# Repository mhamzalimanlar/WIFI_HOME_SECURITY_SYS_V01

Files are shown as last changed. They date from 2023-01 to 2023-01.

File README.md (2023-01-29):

# WIFI_HOME_SECURITY_SYS_V01
 
The system is designed with a 220V AC input and a 12-5V DC output. A DB105STR bridge diode, an STM41T00M6F RTC module for clock information, and a MicroUSB type-B interface are used. The system also features a MAX6662 temperature sensor for indoor temperature control, a TFPT PTC thermistor for outdoor temperature control, and a LHI-878 PIR sensor for motion control in the outdoor environment. The PIR sensor is controlled by a NCS36000 controller. There are two 12V relays for lighting control and an ESP32 WiFi module for wireless communication. Communication between the main microcontroller (STM32f103) and these components is established through the USART, SPI and I2C protocols. The design includes two PCBs: one for the main board and one for the auxiliary sensor board. The boards have 2 layers for signals and 2 layers for power and ground planes, for a total of 4 layers. The design was created using the Altium Designer program.

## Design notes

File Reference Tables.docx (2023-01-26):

Voltage Range (V) | Internal Layers(mil) | External Layers(mil)
0-15 | >1.97 | >3.94
16-30 | >1.97 | >3.94
31-50 | >3.94 | >23.62
51-100 | >3.94 | >23.62
101-150 | >7.87 | >23.62
151-170 | >7.87 | >49.21
171-250 | >7.87 | >49.21
251-300 | >7.87 | >49.21
301-500 | >9.84 | >98.43
>500 | >9.94 | >98.62

Distance Between Lines According To The Voltage Level

Calculated with IPC-2221B VALUES

Capacity Of Current According To The Lınes Wıthdes

Current Capacity(A) | Internal Layers(mil) | External Layers(mil)
<0.94 | 10 | 10
<1.23 | 15 | 15
<1.47 | 20 | 20
<1.69 | 25 | 25
<1.89 | 30 | 30
<2.08 | 35 | 35
<2.25 | 40 | 40
<2.42 | 45 | 45
<2.58 | 50 | 50
<2.73 | 55 | 55
<3.15 | 70 | 70

Calculated with IPC-21525 VALUES (Material FR-4 STD)

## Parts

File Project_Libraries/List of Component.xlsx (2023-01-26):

Comment | Description | Footprint
1N4148WS | Diode, Single, 75 V, 150 mA, 1 V, 4 ns | SOD323F
1SMB5919BT3G | Diode Zener Single 5.6V 5% 3W 2-Pin SMB T/R | SMB
5WD27 | Resistor 5 Watt Cermet Wirewound Flameproof .27 Ohm 5% Axial Lead | RES_AXIAL_W
0603B103K160CT | CAP CER 10nF %10 0603 | CAP_0603
0603B103K160CT | CAP CER 10nF %10 0603 | CAP_0603
10118192-0001LF | CONN RCPT USB2.0 MICRO B SMD R/A | MICRO_B_USB
3413.0216.22 | FUSE BRD MNT 1A 32VAC 63VDC 1206 | 3413.0216.22
64800611622 | 1.50mm 6PIN Connector | 64800611622
78438335470 | FIXED IND 47UH 390MA 2.3 OHM SMD | IND_1212
ABS05-32.768KHZ-T | Crystal, 32.768 kHz, SMD, 1.6mm x 1mm, 12.5 pF, 20 ppm, ABS05 Series | ABS05
ALQ112 | General Purpose Relay SPDT (1 Form C) 12VDC Coil Through Hole | ALQ112
AP7361-33E-13 | LDO Regulator Pos 3.3V 1A 4-Pin(3+Tab) SOT-223 T/R | SOT223
BV302S12010-ZU | 230-12 Transformer 1VA | BV302S
C0603C104K5RACTU | CAP CER 100nF %10 0603 SMD | CAP_0603
C3216X5R1E336M160AC | CAP CER 33uF %20 1206 SMD | CAP_1206
CL10C200JB8NNNC | CAP CER 20pF %5 0603 SMD | CAP_0603
CL21A475KAQNNNE | CAP CER 4.7uF %10 0805 | CAP_0805
CL21B104KBCNNNC | CAP CER 100nF %10 0805 | CAP_0805
CL21B105KBFNNNE | CAP CER 1uF %10 0805 | CAP_0805
CMI-9605IC-0580T | Buzzers Indicator, Internally Driven Magnetic 5V 30mA 2.7kHz 80dB @ 5V, 10cm Through Hole PC Pins | CMI-9605IC
DB105STR | Bridge Diode AC-DC | DB105STR
ECS-160-20-30B-TR | CRYSTAL 16.0000MHZ 20PF SMD | ECS
EEV686M035A9HAA | Cap Aluminum Lytic 68uF 35V 20% (6.3 X 7.7mm) SMD 280mA 2000h 105C T/R | CAP_EEVseries
EG1215AA | Slide Switch, SPDT, 0.025A, 24V, SMD | EG1215AA
ESH477M050AH4AA | CAP ALU ELEC 470uF 50V RADIAL, Cap, 470UF, 50V, Alu Elec, Radial | CAP_RADIAL_D10_P5
ESP32-WROOM-32 | SMD MODULE, ESP32-D0WDQ6, 32MBIT | ESP32-32
LH R974-LP-1 | LED Uni-Color Hyper Red 660nm 2-Pin Chip 0805(2012Metric) T/R | LED_RED_0805
LHI 878/3902 | SENSOR PYRO DETECTOR DUAL MOTION | LHI 878
LM2675MX-12/NOPB | Switching Voltage Regulators Pwr Cnvtr Hi Eff 1A SD Vtg Reg | SOIC8
LTST-C171GKT | Green 0805 130 º Min 5 mcd Typical 12 mcd Water Clear Lens SMT LED | LED_GREEN_0805
M41T00M6F | IC RTC CLK/CALENDAR I2C 8-SOIC | SOIC8
MAX6662 | SENSOR TEMPERATURE SPI 8SOIC | SOIC8
MMBT3904-7-F | Transistor General Purpose BJT NPN 40 Volt 0.2A Automotive 3-Pin SOT-23 | SOT-23F
NCS36000DRG | PIR Controller Low Noise Amplifiers and LDO Regulator 14-Pin SOIC N T/R | SOIC14
OPA314AIDBVR | Op Amp OPA314 | SOT23-5
PJ-037AH-SMT-TR | DC Power Connectors Power Jacks | JACK
RC0603FR-0710KL | RES 1K %1 OHM 0603 SMD, RES 10K %1 OHM 0603 SMD | RES_0603
RC0603JR-070RL | RES 0 %1 OHM 0603 SMD | RES_0603
RC0603JR-074K7L | RES 4K7 %5 OHM 0603 SMD | RES_0603
RC0603JR-0715RL | RES 15 %5 OHM 0603 SMD | RES_0603
RC0603JR-0743KL | RES 43K %5 OHM 0603 SMD | RES_0603
RC0603JR-07100RL | RES 100 %5 OHM 0603 SMD | RES_0603
RC0603JR-07220KL | RES 220K %5 OHM 0603 SMD | RES_0603
RC0603JR-07560KL | RES SMD 560K OHM 5% 1/10W 0603 | RES_0603
SMH-105-02-L-S | .100 C.L. HORIZONTAL SMT SOCKET | PINHEADER1X5_RA
STM32F103C6T6A | MCU 32-bit STM32F ARM Cortex M3 RISC 32KB Flash 2.5V/3.3V 48-Pin LQFP Tray | LQFP-48
TBP01R1-508-02BE | Conn Shrouded Header HDR 2 POS 5.08mm Solder RA Side Entry Thru-Hole Bag | TBP01R1-508
TFPT1206L1002FM | Thermistor PTC 10K Ohm 1% 1206 | RES_1206
USBLC6-2SC6 | TVS DIODE 5.25V 17V SOT23-6 | SOT23-6L

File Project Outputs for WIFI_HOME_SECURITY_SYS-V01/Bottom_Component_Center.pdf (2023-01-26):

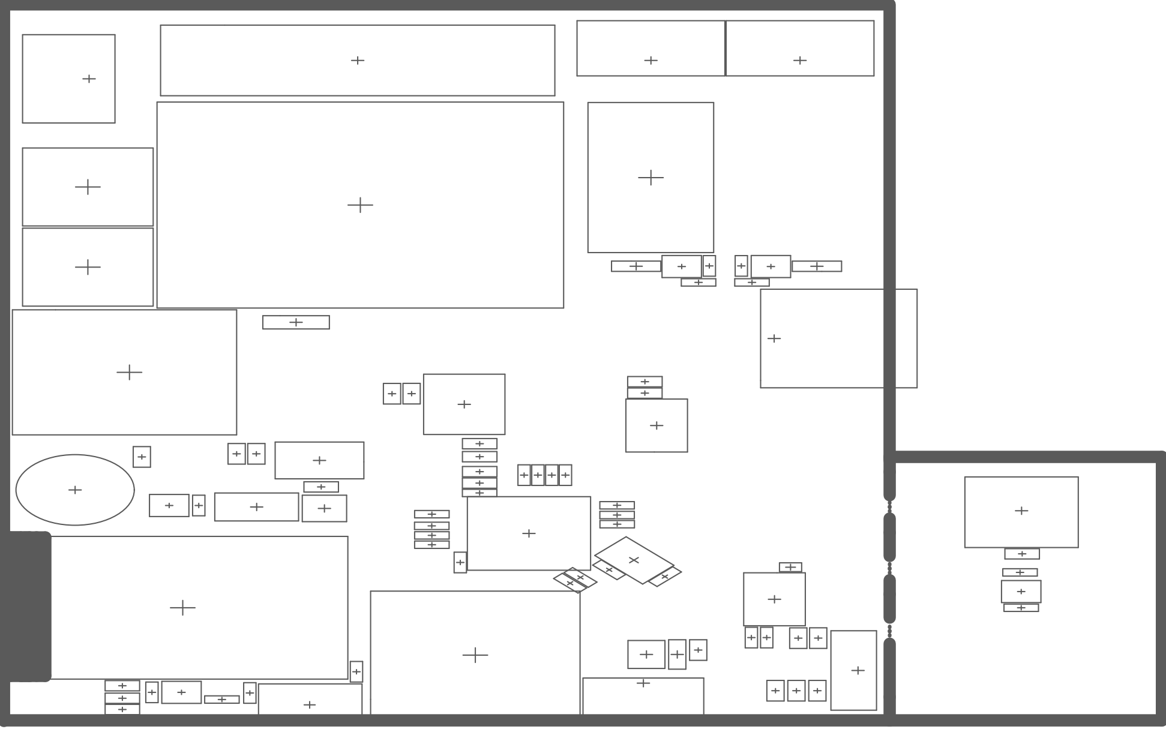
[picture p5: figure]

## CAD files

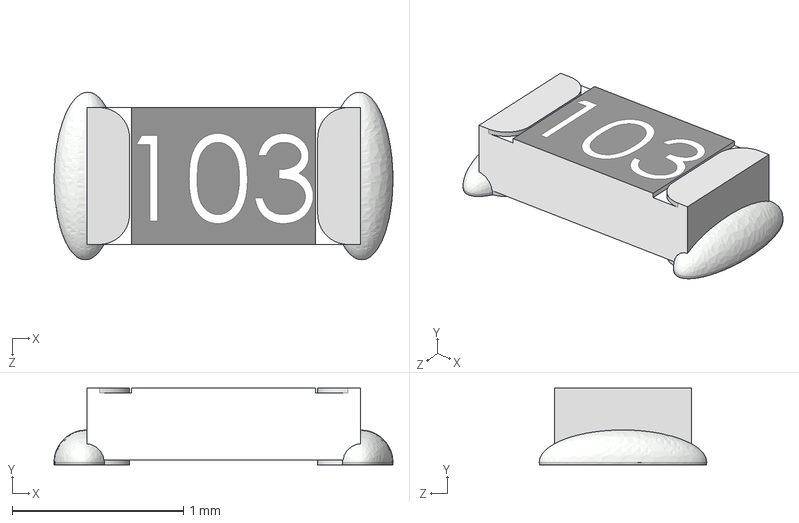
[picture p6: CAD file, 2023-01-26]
Project_Libraries/Steps/0603S1.STEP
1.98 x 0.45 x 0.979 mm

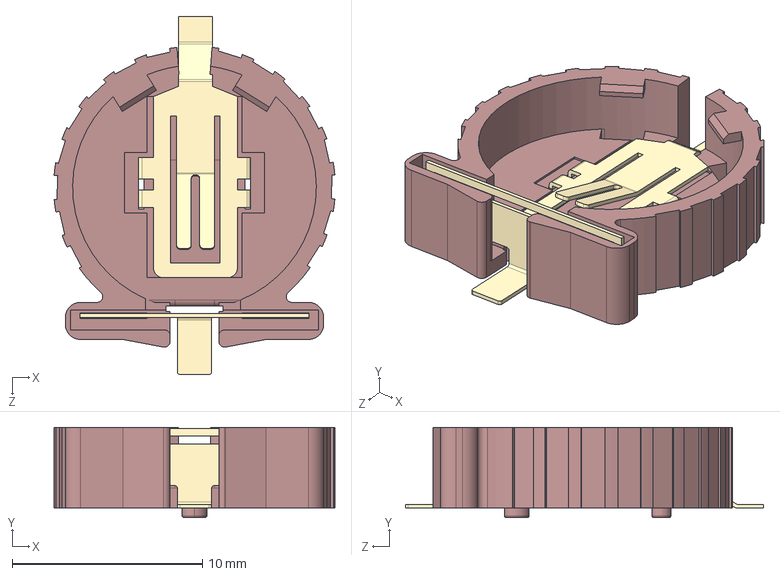
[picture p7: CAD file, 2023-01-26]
Project_Libraries/Steps/User Library-Battery Holder for CR1220 SMD.step
14.7 x 4.75 x 18.8 mm

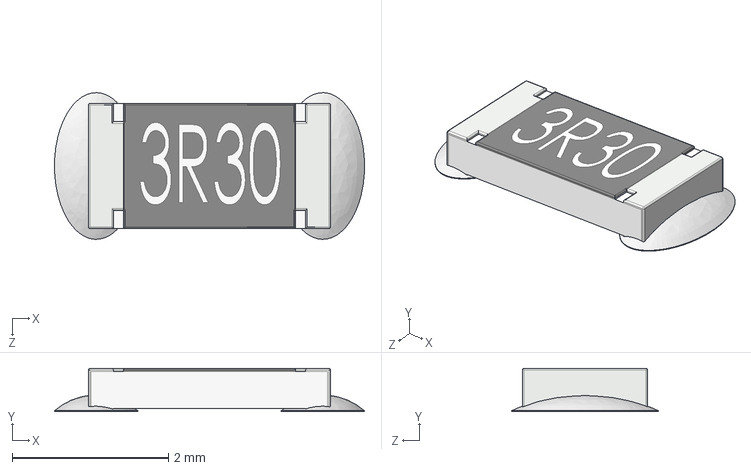
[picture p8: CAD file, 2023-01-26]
Project_Libraries/Steps/res1206r.STEP
3.97 x 0.551 x 1.88 mm

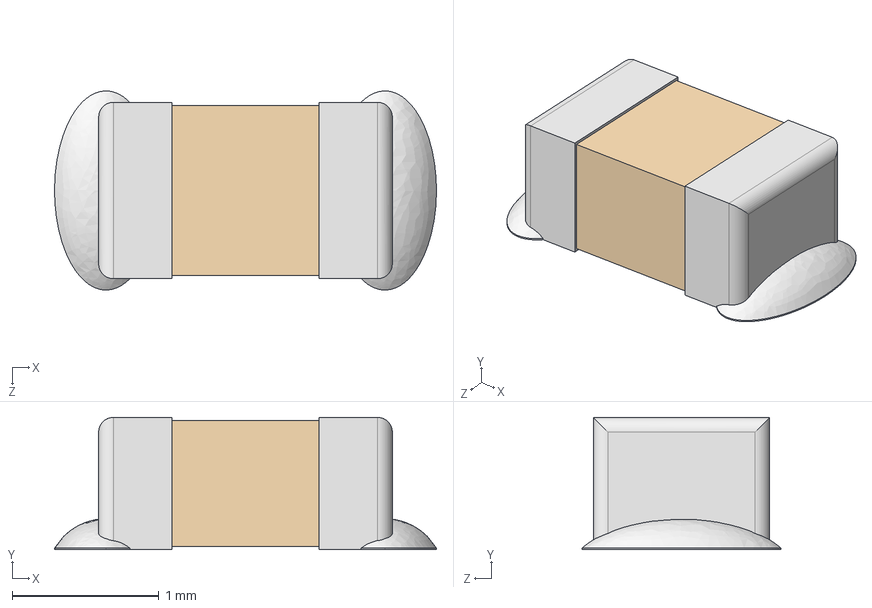
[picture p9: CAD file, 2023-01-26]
Project_Libraries/Steps/CAPC0805.STEP
2.60 x 0.9 x 1.36 mm

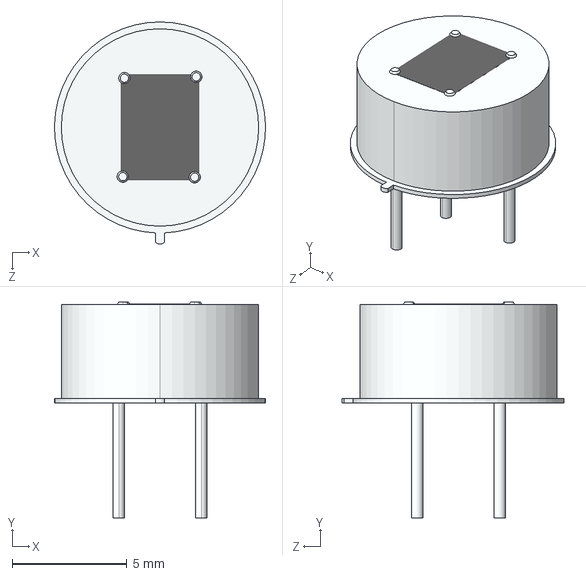
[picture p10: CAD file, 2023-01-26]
Project_Libraries/Steps/Library-LHI878-1.step
9.20 x 9.40 x 9.68 mm

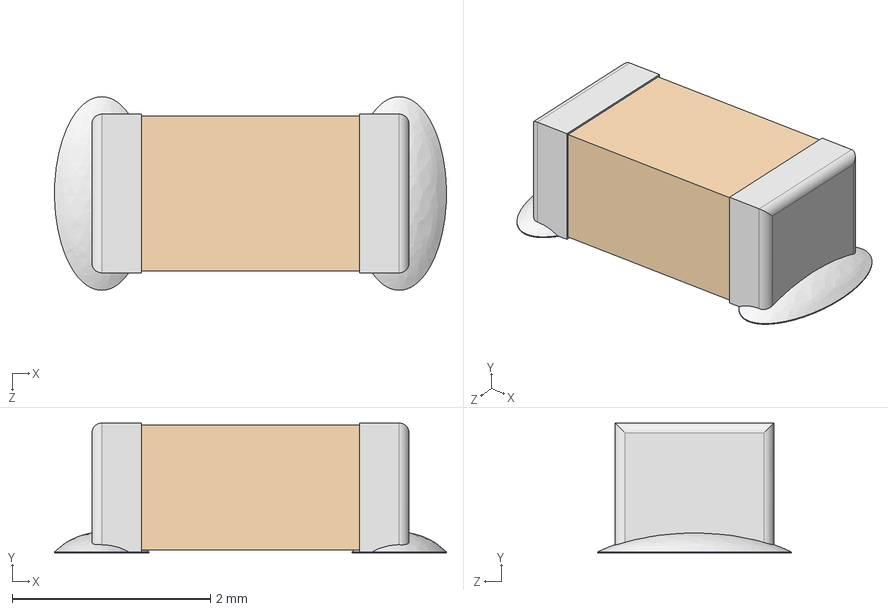
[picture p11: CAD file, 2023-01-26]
Project_Libraries/Steps/CAPC1206.STEP
3.95 x 1.31 x 1.95 mm

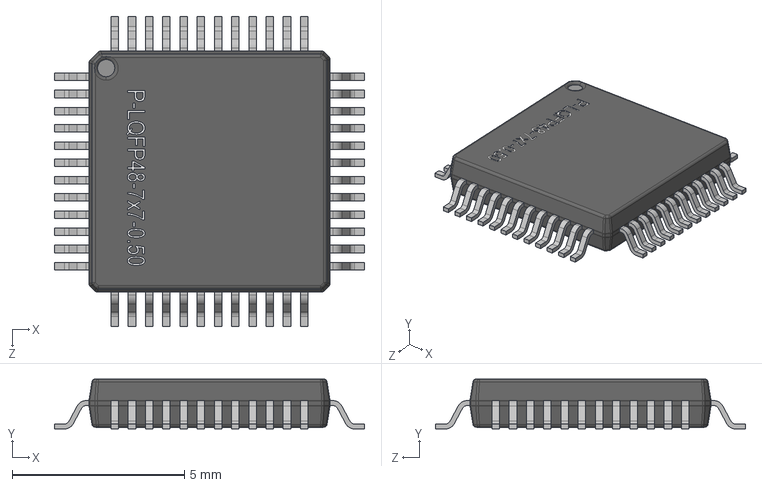
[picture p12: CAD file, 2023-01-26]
Project_Libraries/Steps/Library-P-LQFP48-7x7-0_50.step
9.00 x 1.45 x 9.00 mm

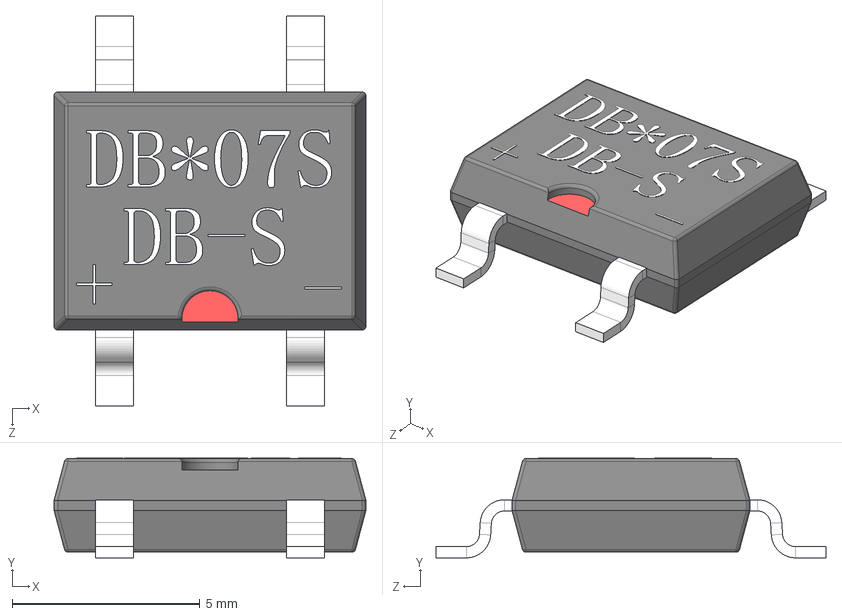
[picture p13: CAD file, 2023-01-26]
Project_Libraries/Steps/Library-DB107S DB-S.step
8.32 x 2.66 x 10.4 mm

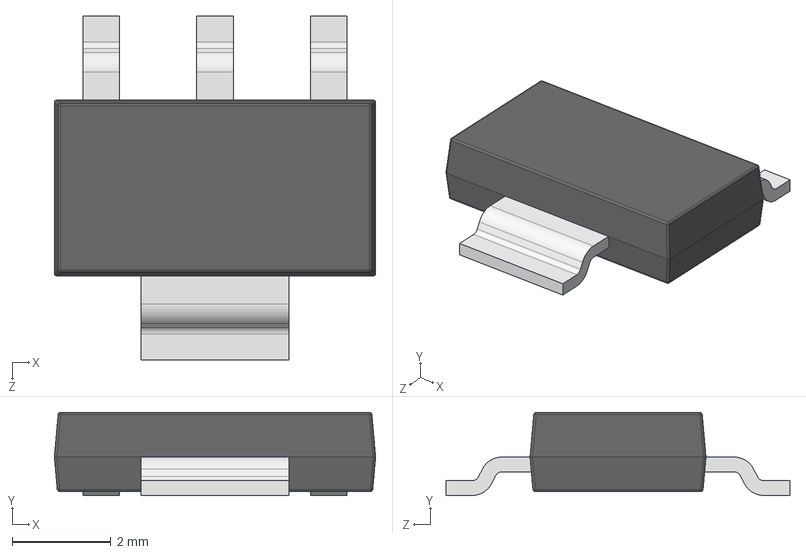
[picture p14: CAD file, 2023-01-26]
Project_Libraries/Steps/SOT-223.step
6.50 x 1.68 x 6.96 mm

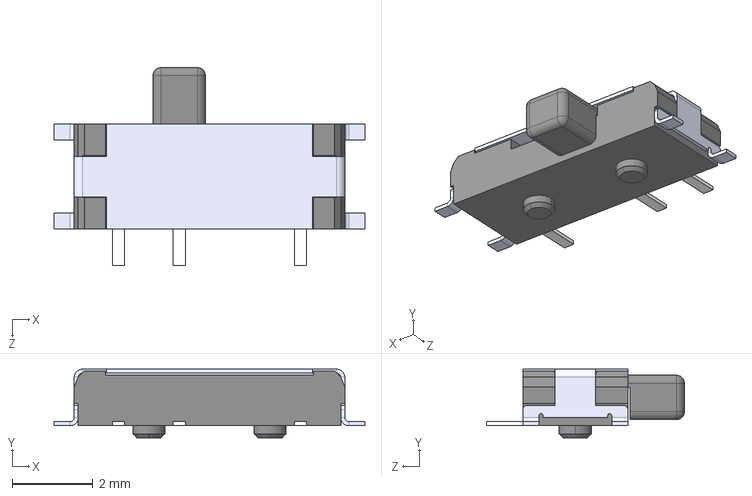
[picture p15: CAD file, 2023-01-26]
Project_Libraries/Steps/EG1215AA--3DModel-STEP-1.STEP
7.70 x 1.70 x 4.90 mm

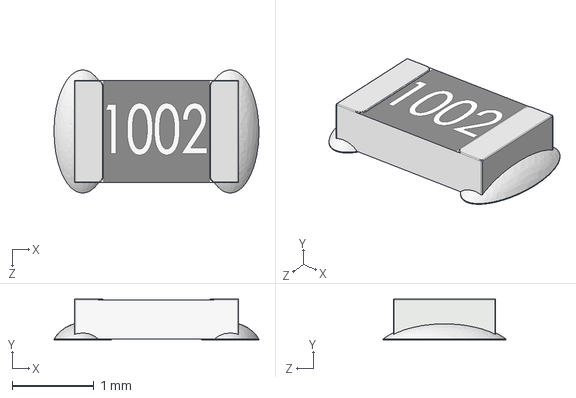
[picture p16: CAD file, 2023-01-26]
Project_Libraries/Steps/res0805.STEP
2.50 x 0.5 x 1.50 mm

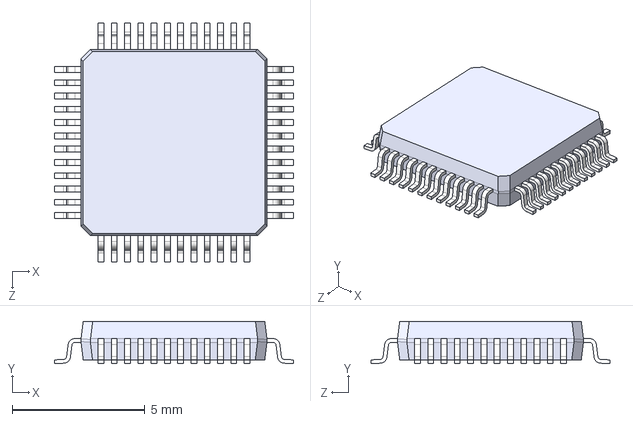
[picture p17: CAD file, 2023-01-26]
Project_Libraries/Steps/STM32F103C6T6A.STEP
9.00 x 1.60 x 9.00 mm

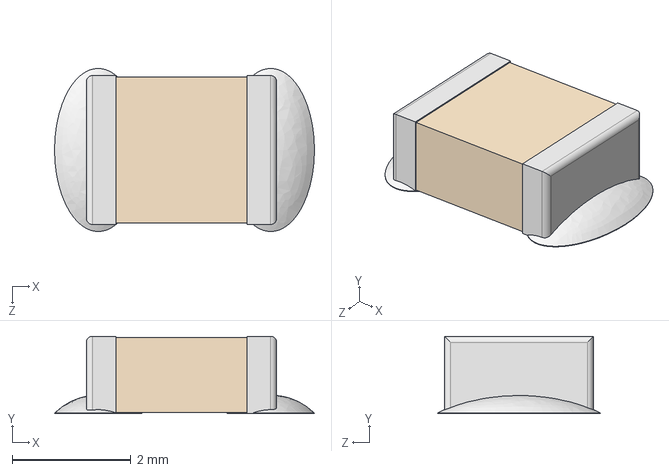
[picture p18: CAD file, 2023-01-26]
Project_Libraries/Steps/CAPC1210.STEP
4.37 x 1.30 x 2.74 mm

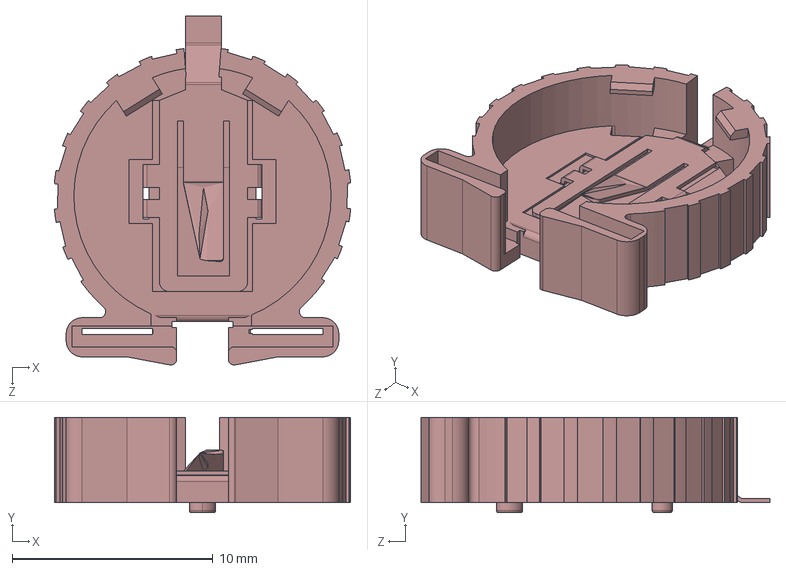
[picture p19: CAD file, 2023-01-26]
Project_Libraries/Steps/Library-1056.step
14.7 x 4.75 x 17.4 mm

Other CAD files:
Project_Libraries/Steps/LM2675M-12.STEP
Project_Libraries/Steps/Library-SOT23F-1.STEP
Project_Libraries/Steps/CAPC0603.STEP
Project_Libraries/Steps/Library-Hahn BV EI 302 2902.step
Project_Libraries/Steps/7447709001_Download_WE-PD_1210_STP_rev1_WE_INDUCTOR.stp
Project_Libraries/Steps/B82477G4472M000_COIL.STEP
Project_Libraries/Steps/STM32 LQFP48.step

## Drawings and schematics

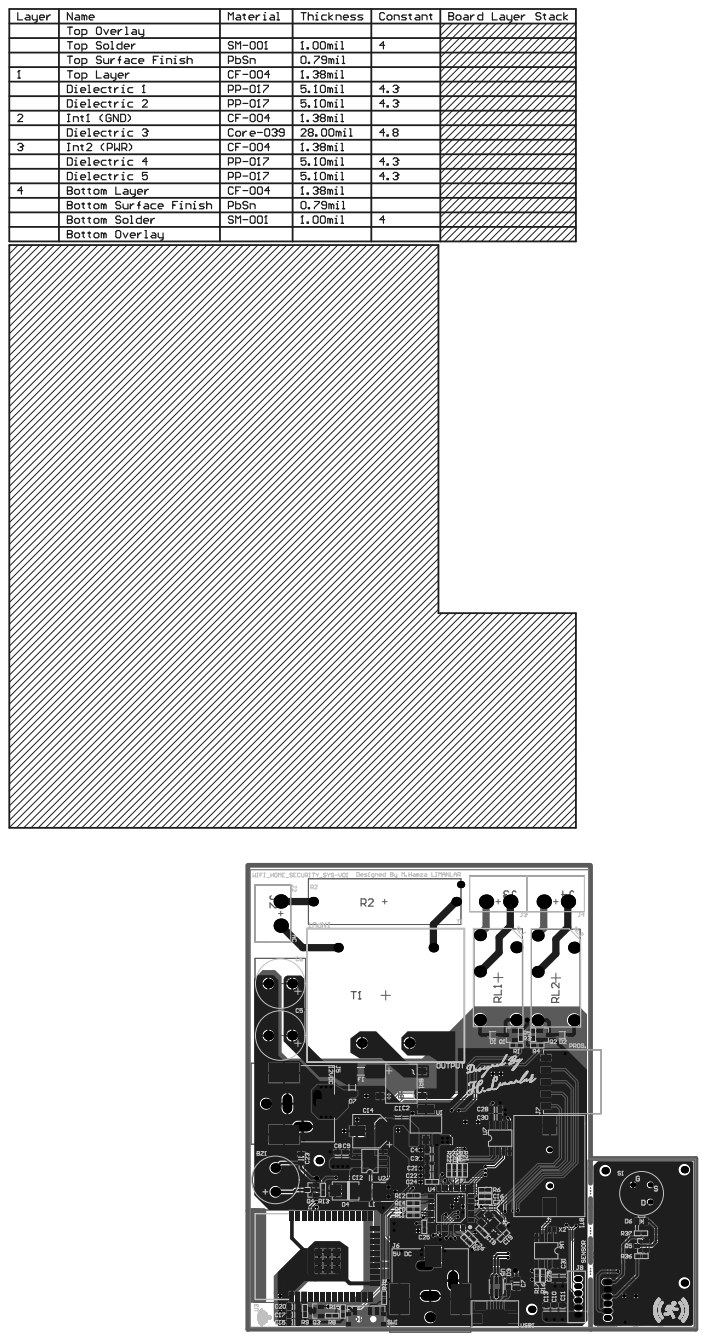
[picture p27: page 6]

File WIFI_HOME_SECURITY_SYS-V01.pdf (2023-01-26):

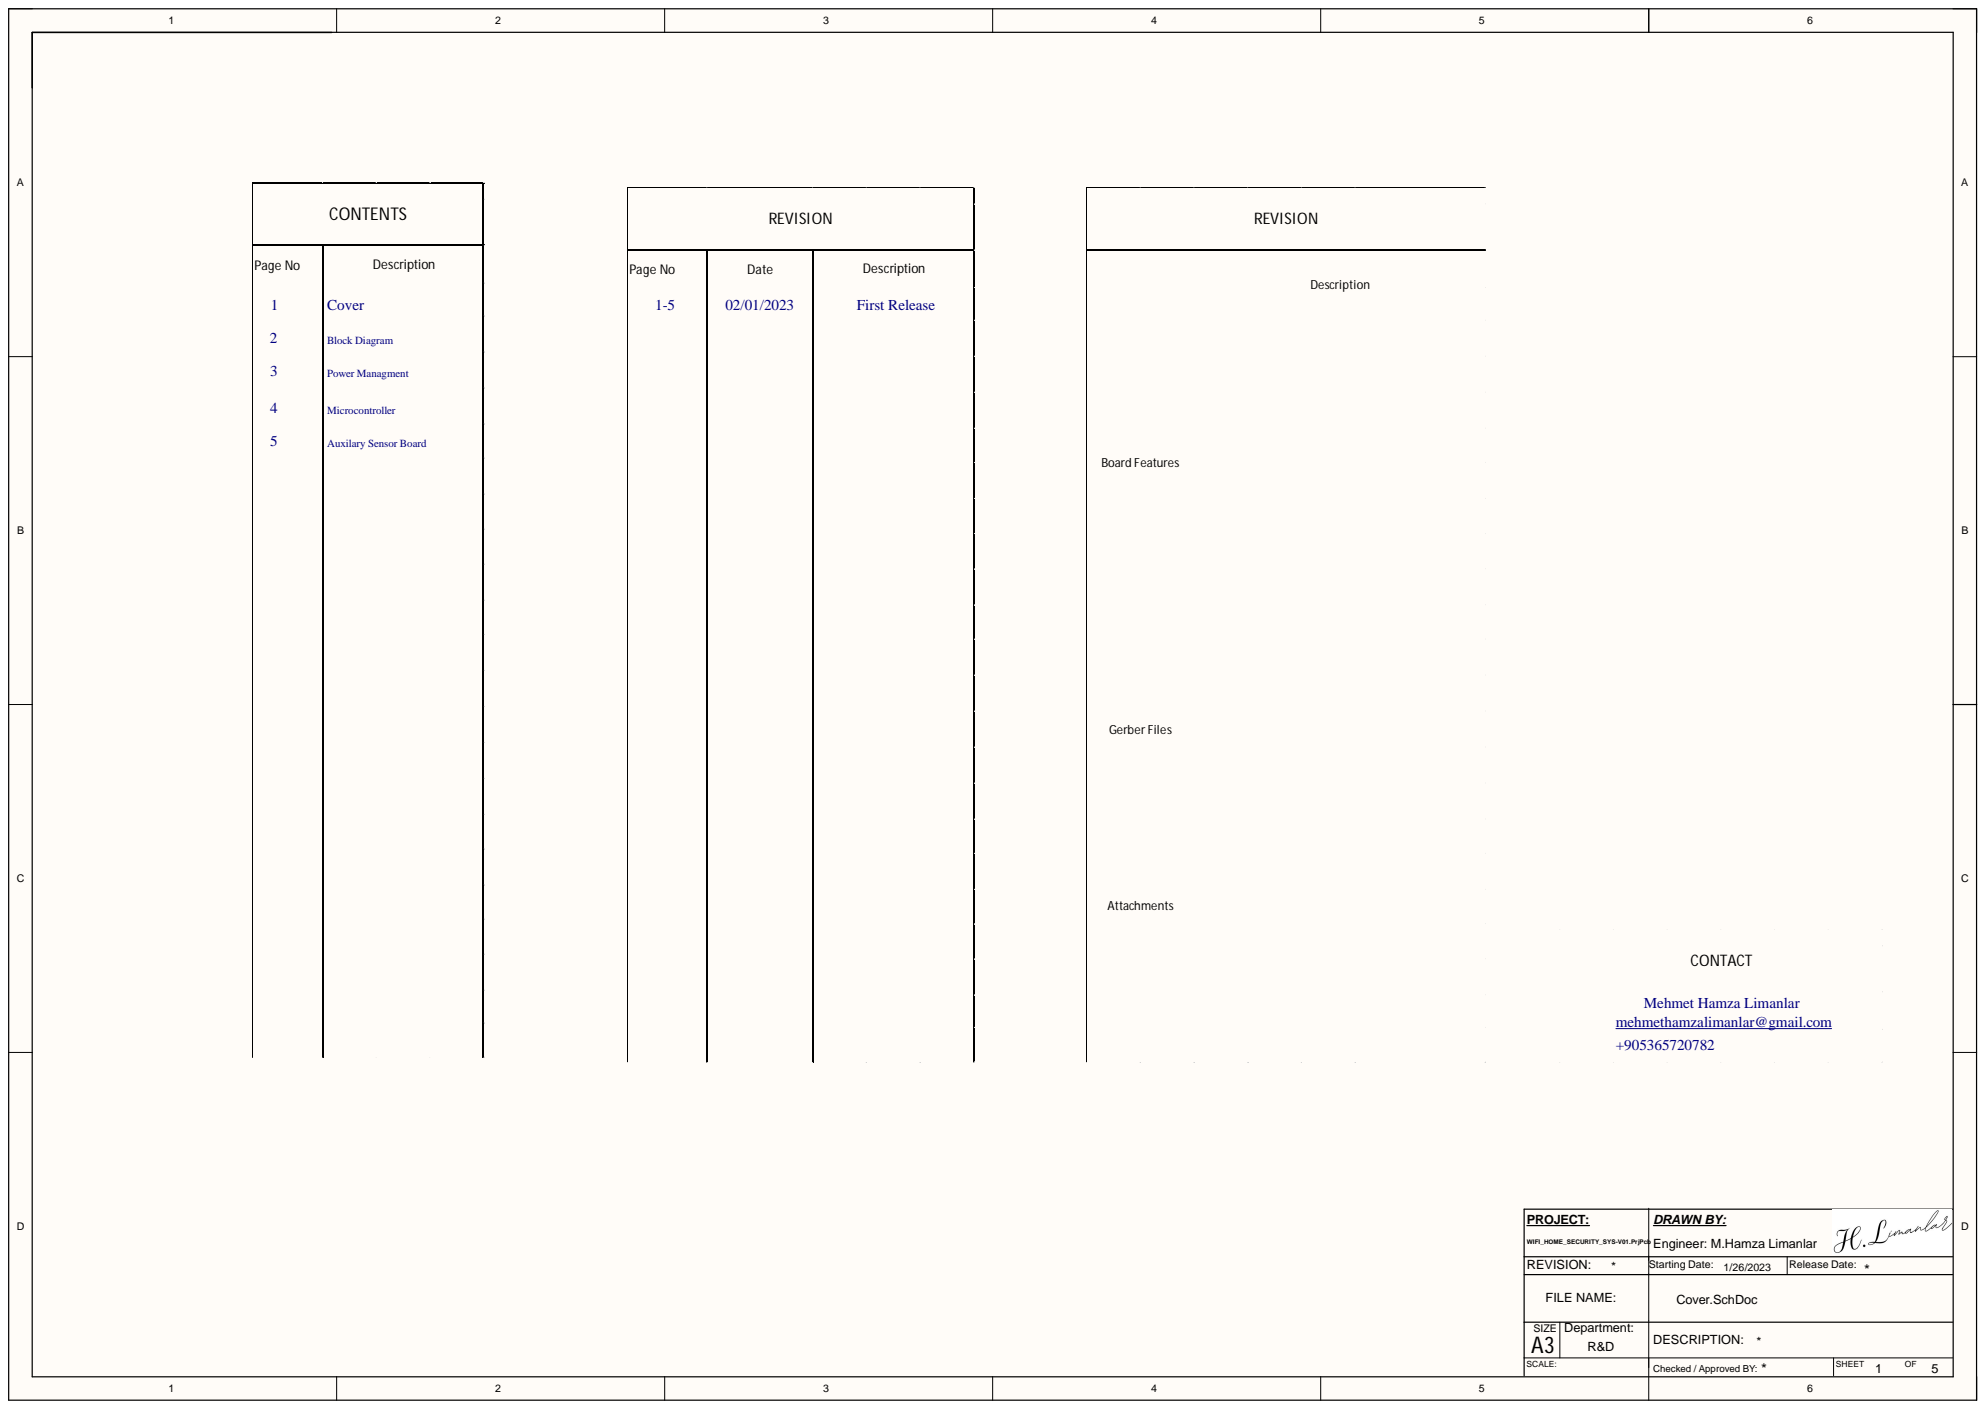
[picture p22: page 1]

PROJECT: WIFI_HOME_SECURITY_SYS-V01.PrjPcb | DRAWN BY: Engineer: M.Hamza Limanlar

REVISION: * | Starting Date: 1/26/2023 | Release Date: *

FILE NAME: | Cover.SchDoc
SIZE A3 | Department: R&D | DESCRIPTION: *

SCALE: | Checked / Approved BY: * | SHEET OF 5

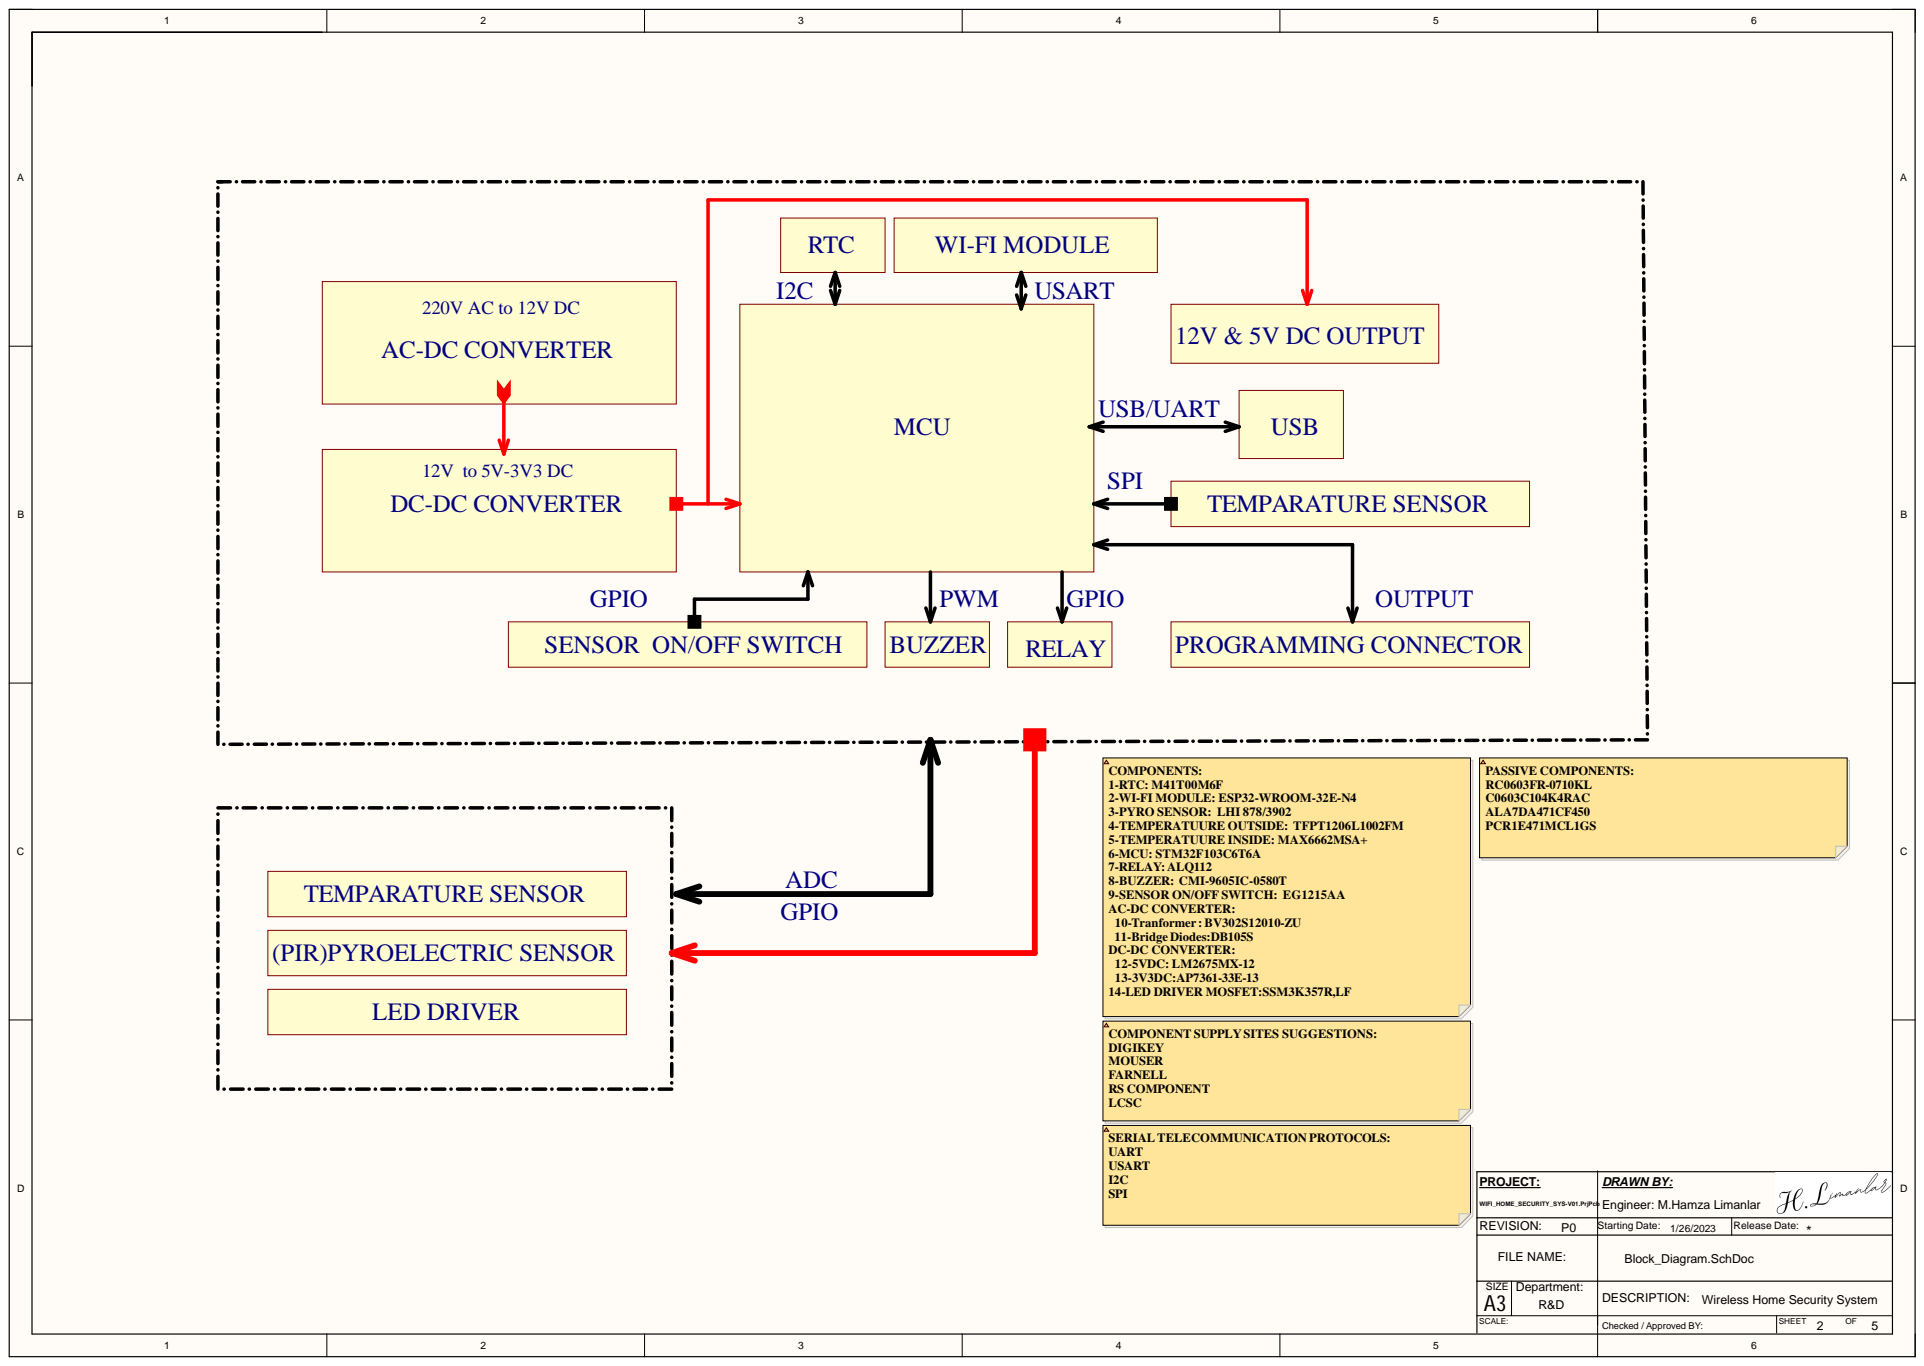
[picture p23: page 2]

COMPONENTS:
1-RTC: M41T00M6F
2-WI-FI MODULE: ESP32-WROOM-32E-N4
3-PYRO SENSOR: LHI 878/3902
4-TEMPERATUURE OUTSIDE: TFPT1206L1002FM
5-TEMPERATUURE INSIDE: MAX6662MSA+
6-MCU: STM32F103C6T6A
7-RELAY: ALQ112
8-BUZZER: CMI-9605IC-0580T
9-SENSOR ON/OFF SWITCH: EG1215AA
AC-DC CONVERTER:
10-Tranformer : BV302S12010-ZU
11-Bridge Diodes:DB105S
DC-DC CONVERTER:
12-5VDC: LM2675MX-12
14-LED DRIVER MOSFET:SSM3K357R,LF

PROJECT: WIFI_HOME_SECURITY_SYS-V01.PrjPcb | DRAWN BY: Engineer: M.Hamza Limanlar

REVISION: P0 | Starting Date: 1/26/2023 | Release Date: *

FILE NAME: | Block_Diagram.SchDoc
SIZE A3 | Department: | DESCRIPTION: Wireless Home Security System

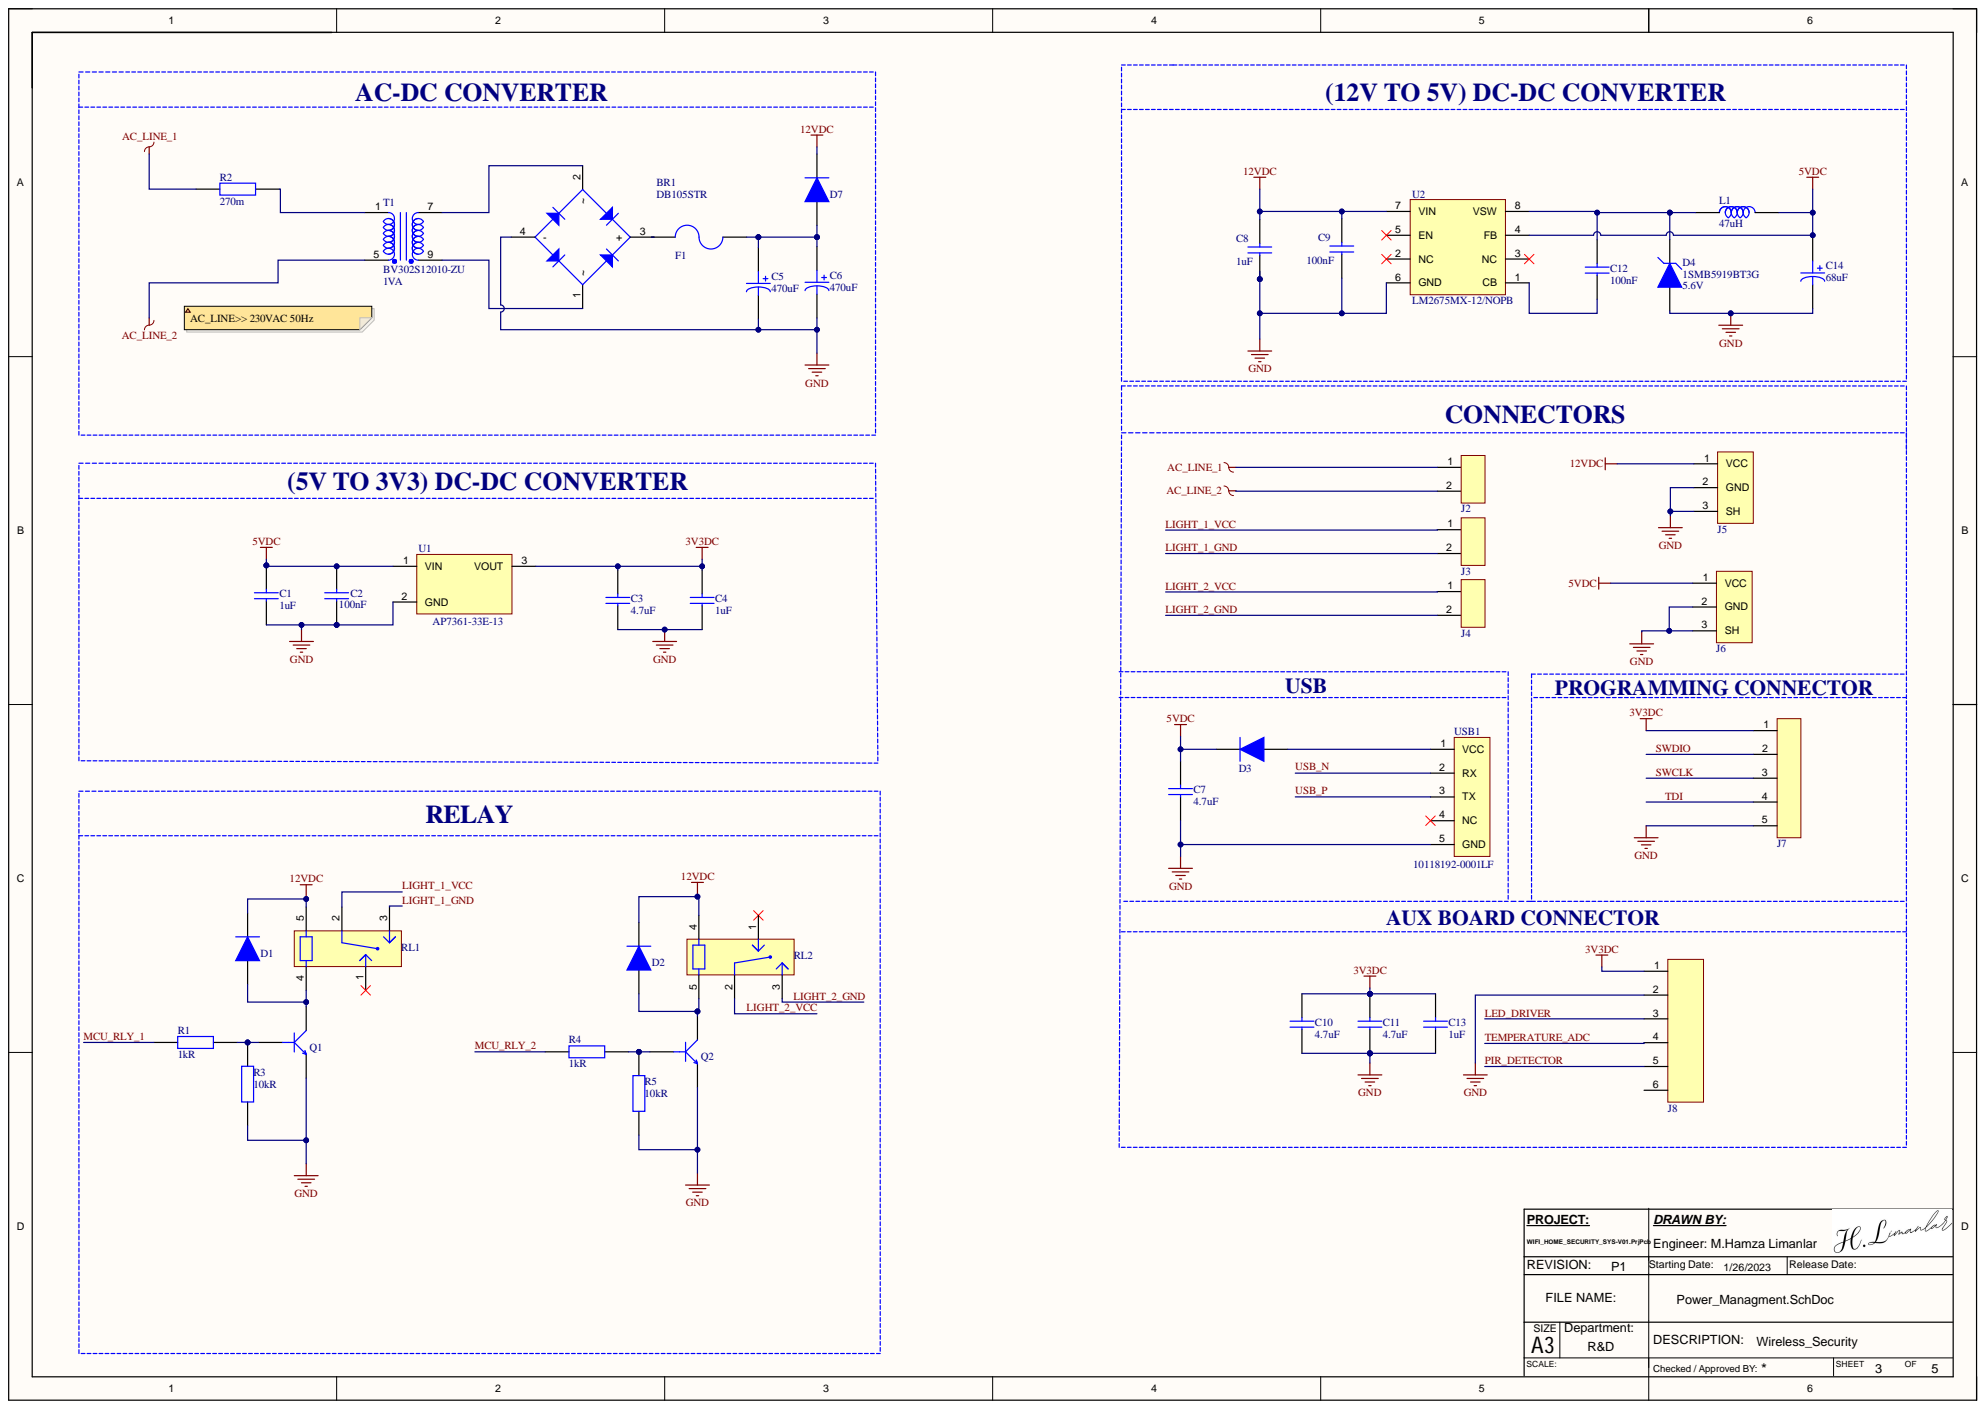
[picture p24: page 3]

(12V TO 5V) DC-DC CONVERTER

(5V TO 3V3) DC-DC CONVERTER

REVISION: P1 | Starting Date: 1/26/2023 | Release Date:

FILE NAME: | Power_Managment.SchDoc
SIZE A3 | Department: | DESCRIPTION: Wireless_Security

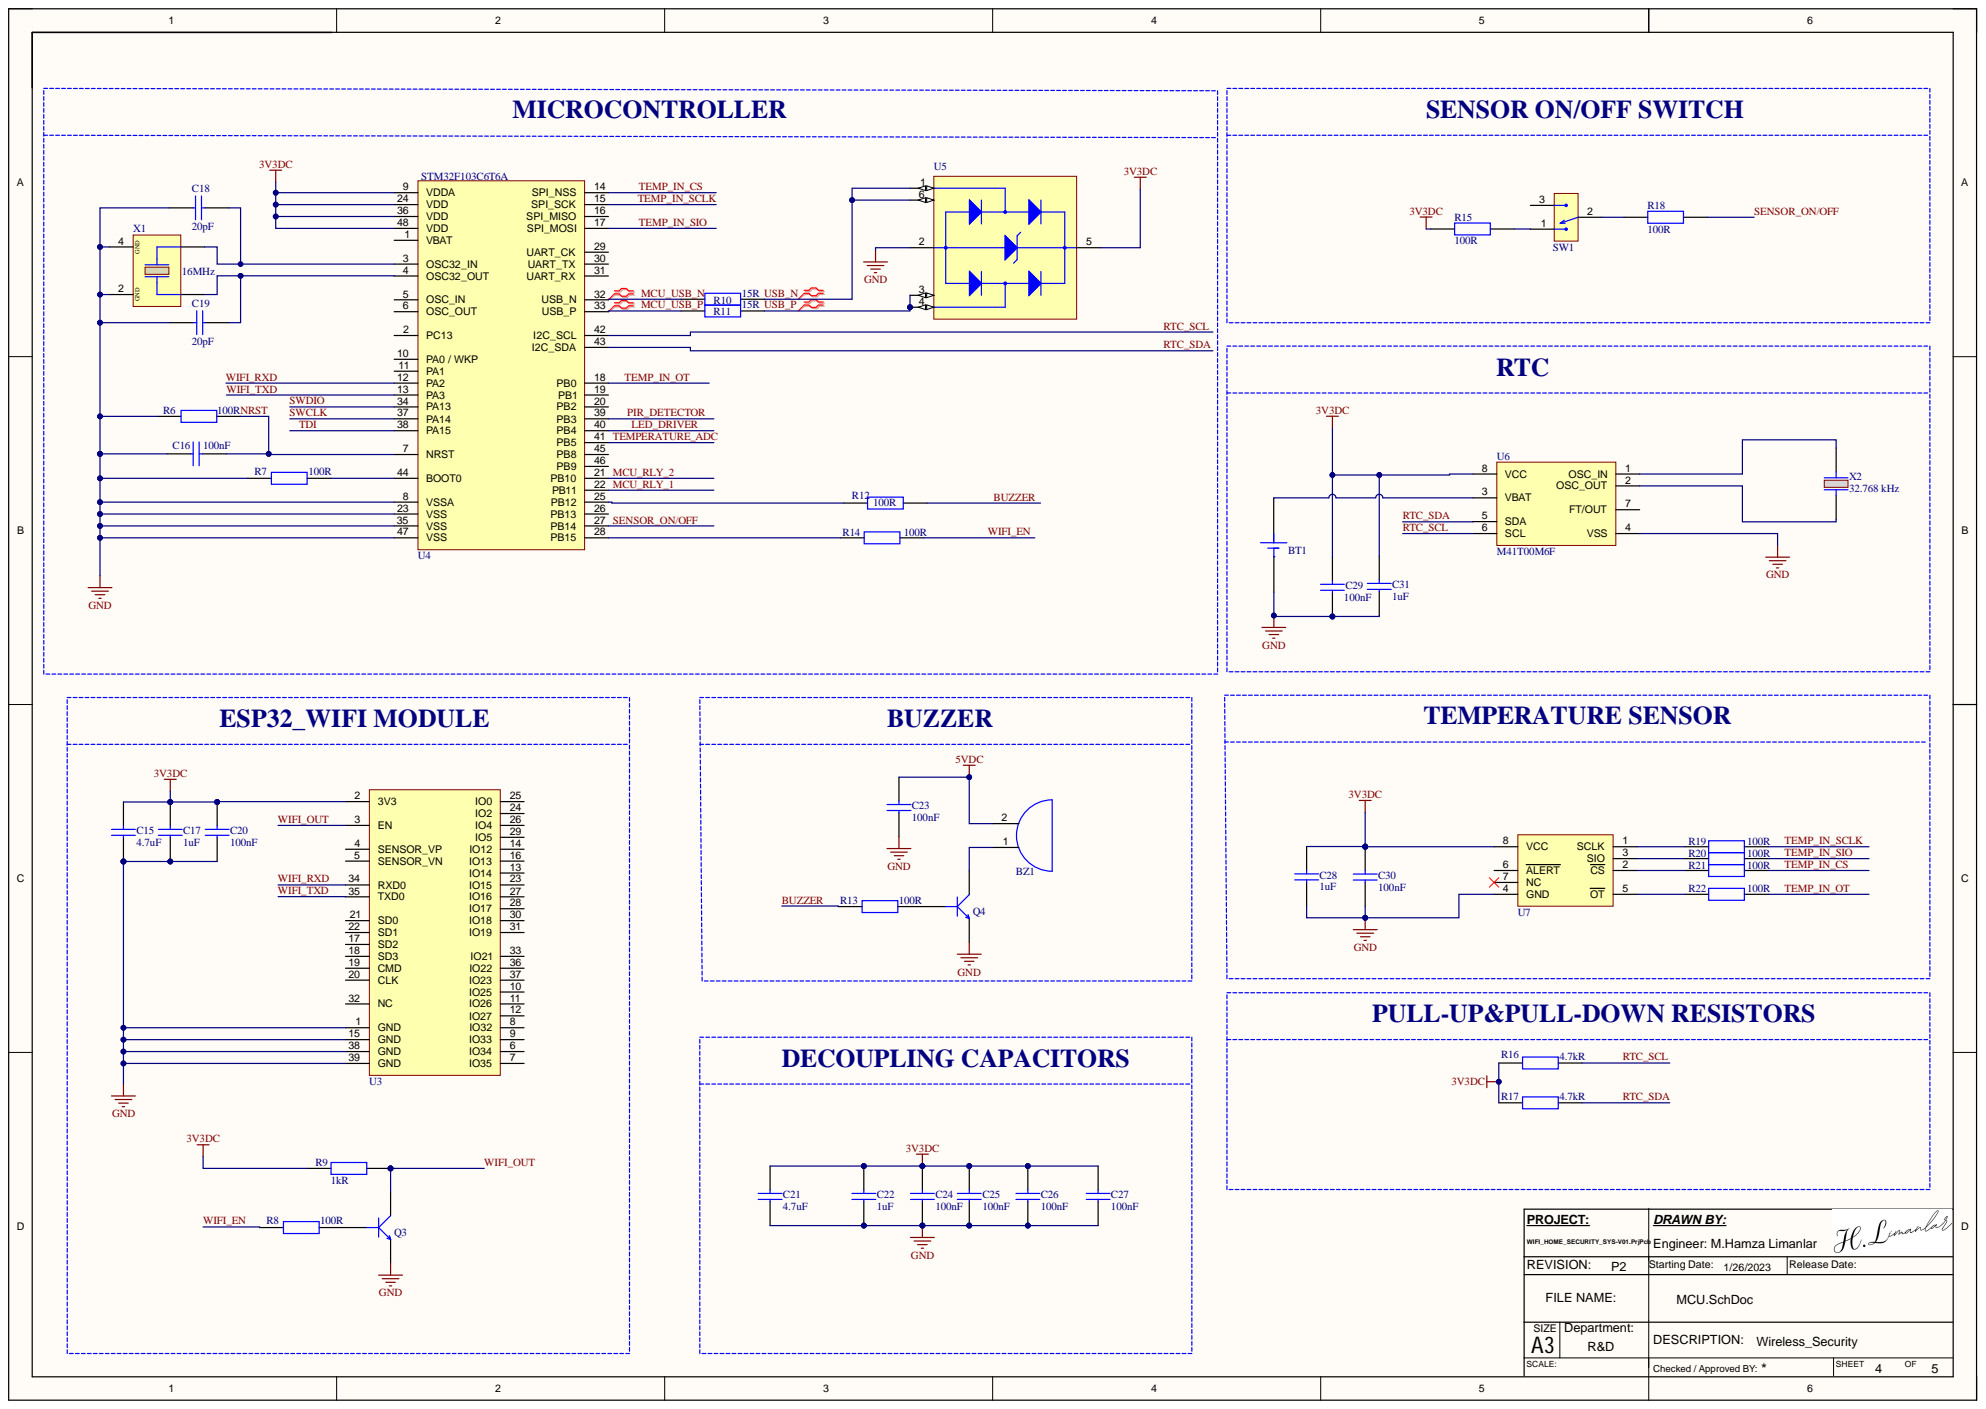
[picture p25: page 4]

SENSOR ON/OFF SWITCH

OSC32_OUT 4

OSC_OUT 6 | MCU_USB_P | 15R R10 15R R11 | USB_P | 4
OSC_IN 5

BOOT0 44

VSS 23 | | SCL 6
VSS 35
VSS 47

PULL-UP&PULL-DOWN RESISTORS

PROJECT: WIFI_HOME_SECURITY_SYS-V01.PrjPcb | DRAWN BY: Engineer: M.Hamza Limanlar

REVISION: P2 | Starting Date: 1/26/2023 | Release Date:

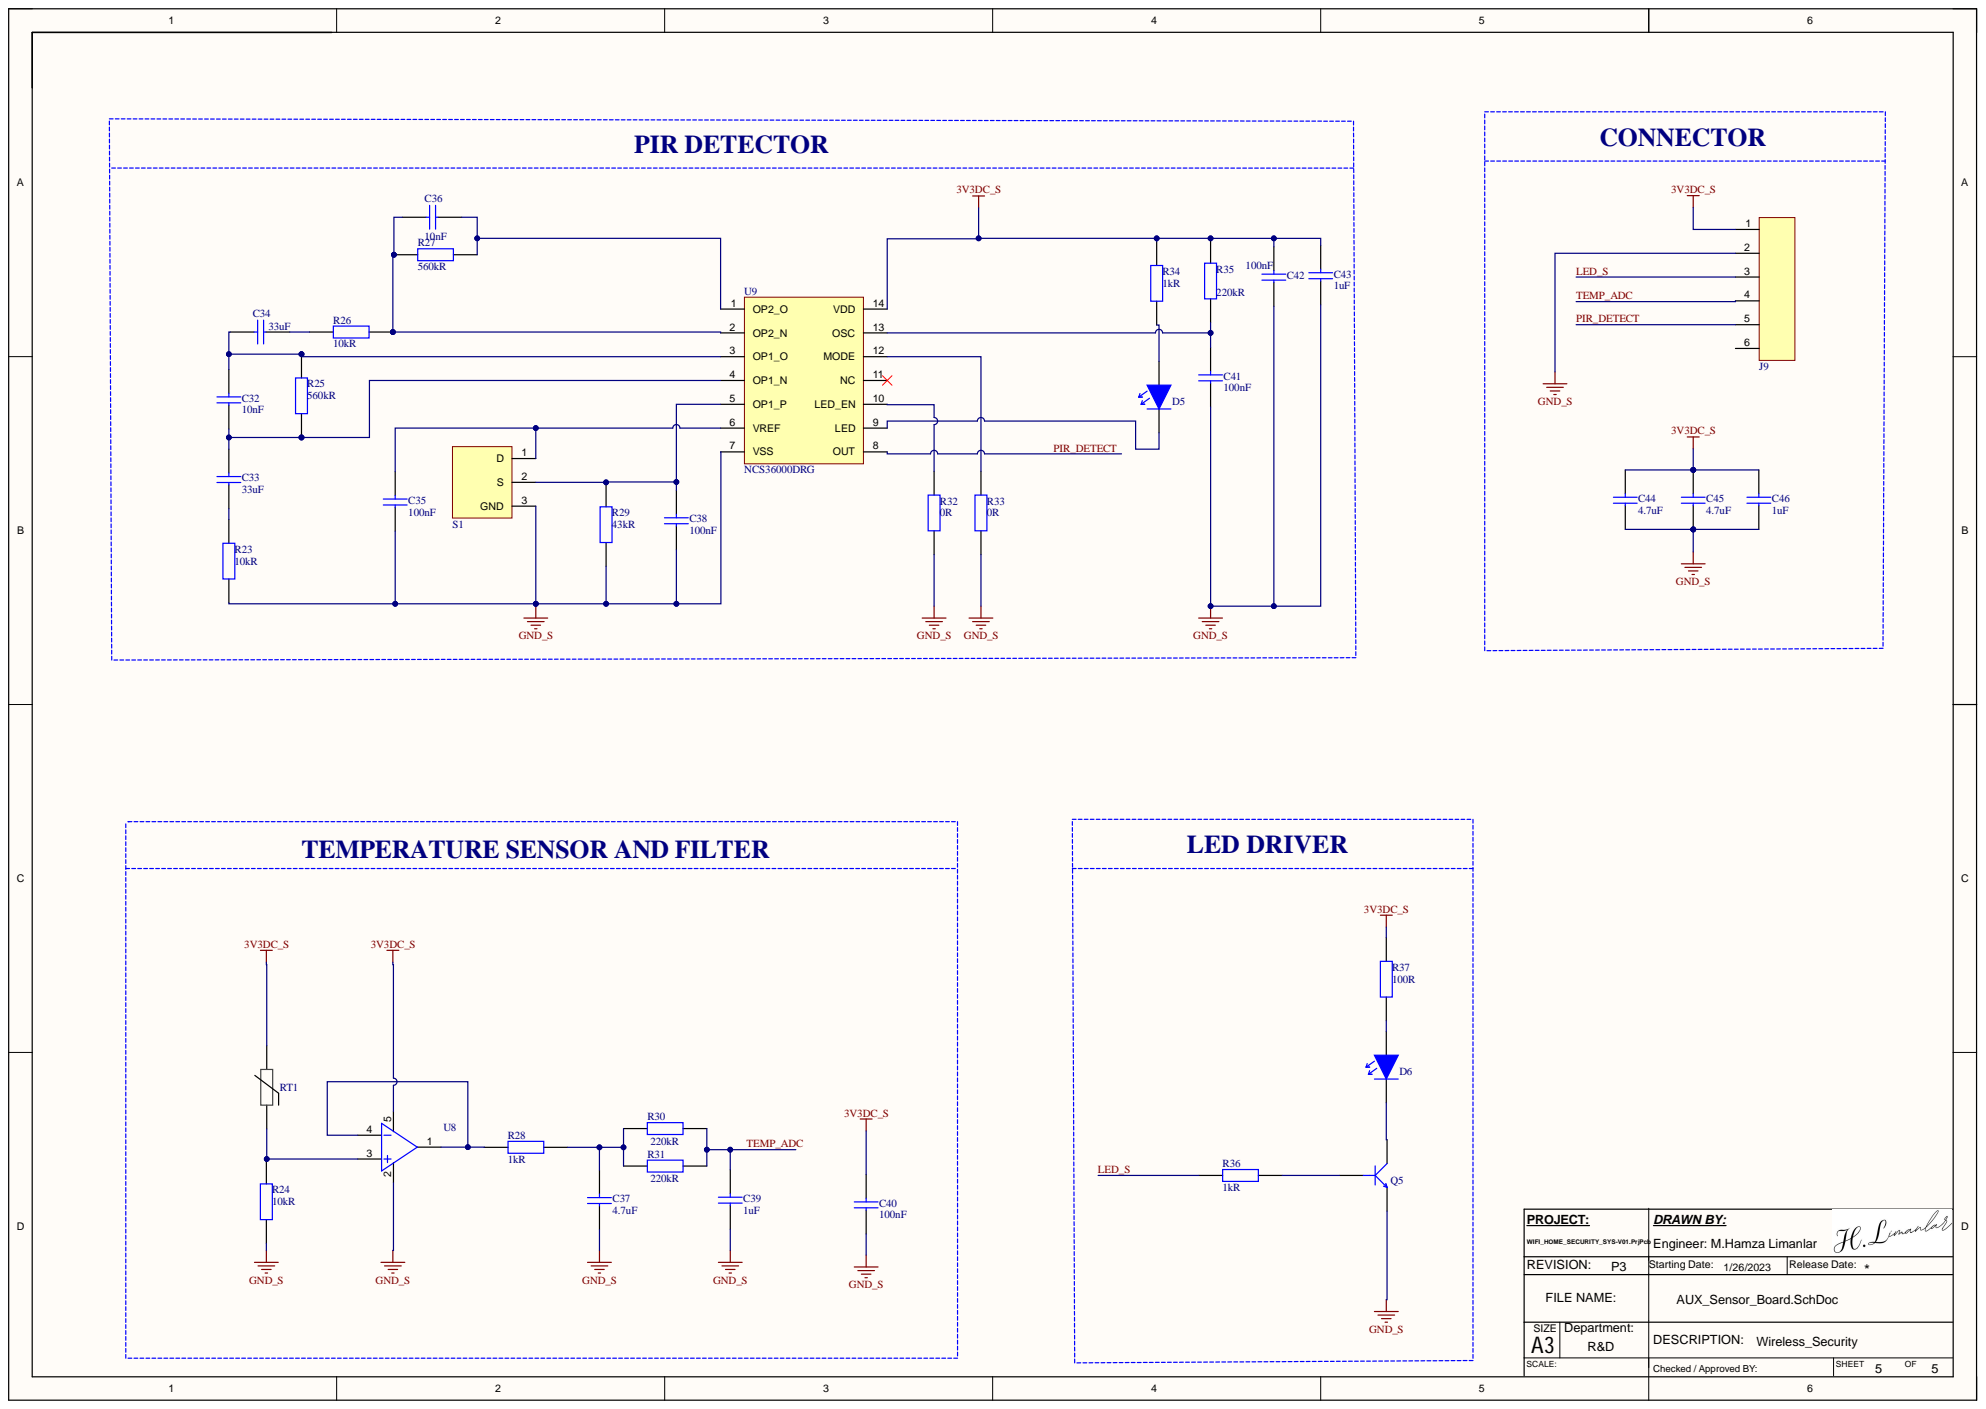
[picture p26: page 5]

TEMPERATURE SENSOR AND FILTER

PROJECT: WIFI_HOME_SECURITY_SYS-V01.PrjPcb | DRAWN BY: Engineer: M.Hamza Limanlar

REVISION: P3 | Starting Date: 1/26/2023 | Release Date: *

FILE NAME: | AUX_Sensor_Board.SchDoc
SIZE A3 | Department: | DESCRIPTION: Wireless_Security
